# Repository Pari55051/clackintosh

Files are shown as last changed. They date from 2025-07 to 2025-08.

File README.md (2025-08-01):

# Clackintosh
a wireless mechanical keyboard, with 75% layout (81 keys) and a rotary encoder. 
this accompanies my other hardware projects, namely, Clackinntosh Jr. (a macropad), Clackade (a small, very basic PCB-based game console), and Clickster (mouse based on Bambu Lab's Mouse Kit)

## Features
- 75% layout (81 keys) + a rotary encoder
- based on nice!nano v2 MCU
- has underglow LEDs to light up the side-printed keycaps
- hotswappable switches (Cherry MX Red/Brown)
- wireless with 10000mah battery
- ~ 4° tilt for ergonomics
- ZMK firmware
- a blank white case to put some stickers on it!
- an accompanying wristrest

## Images

## General
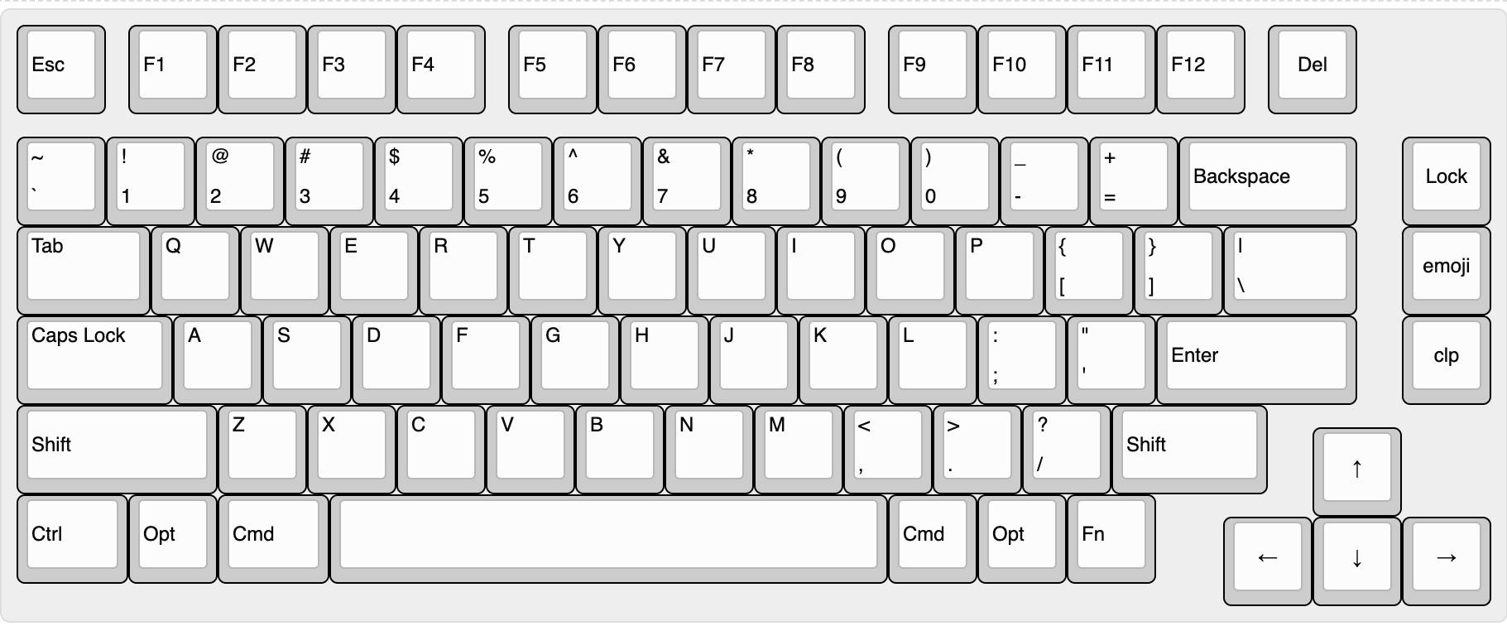
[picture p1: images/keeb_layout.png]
keeb layout

> not the assembled version, i'm hoping for it to look like this with the keycap set
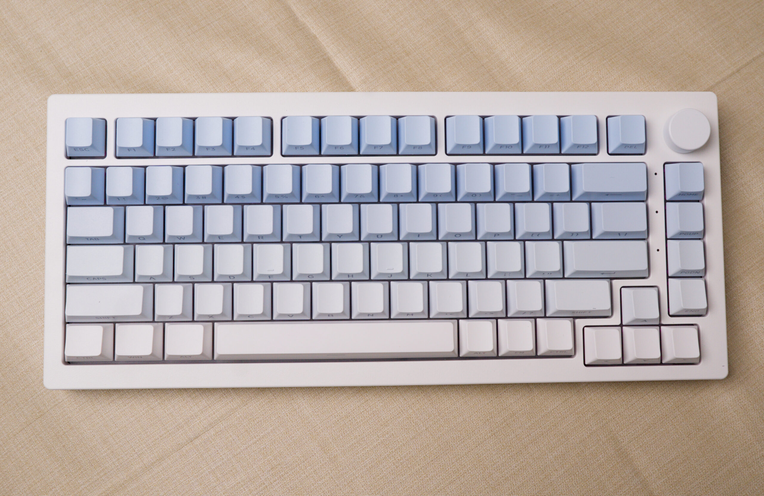
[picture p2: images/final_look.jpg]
wanted look


### Schematic
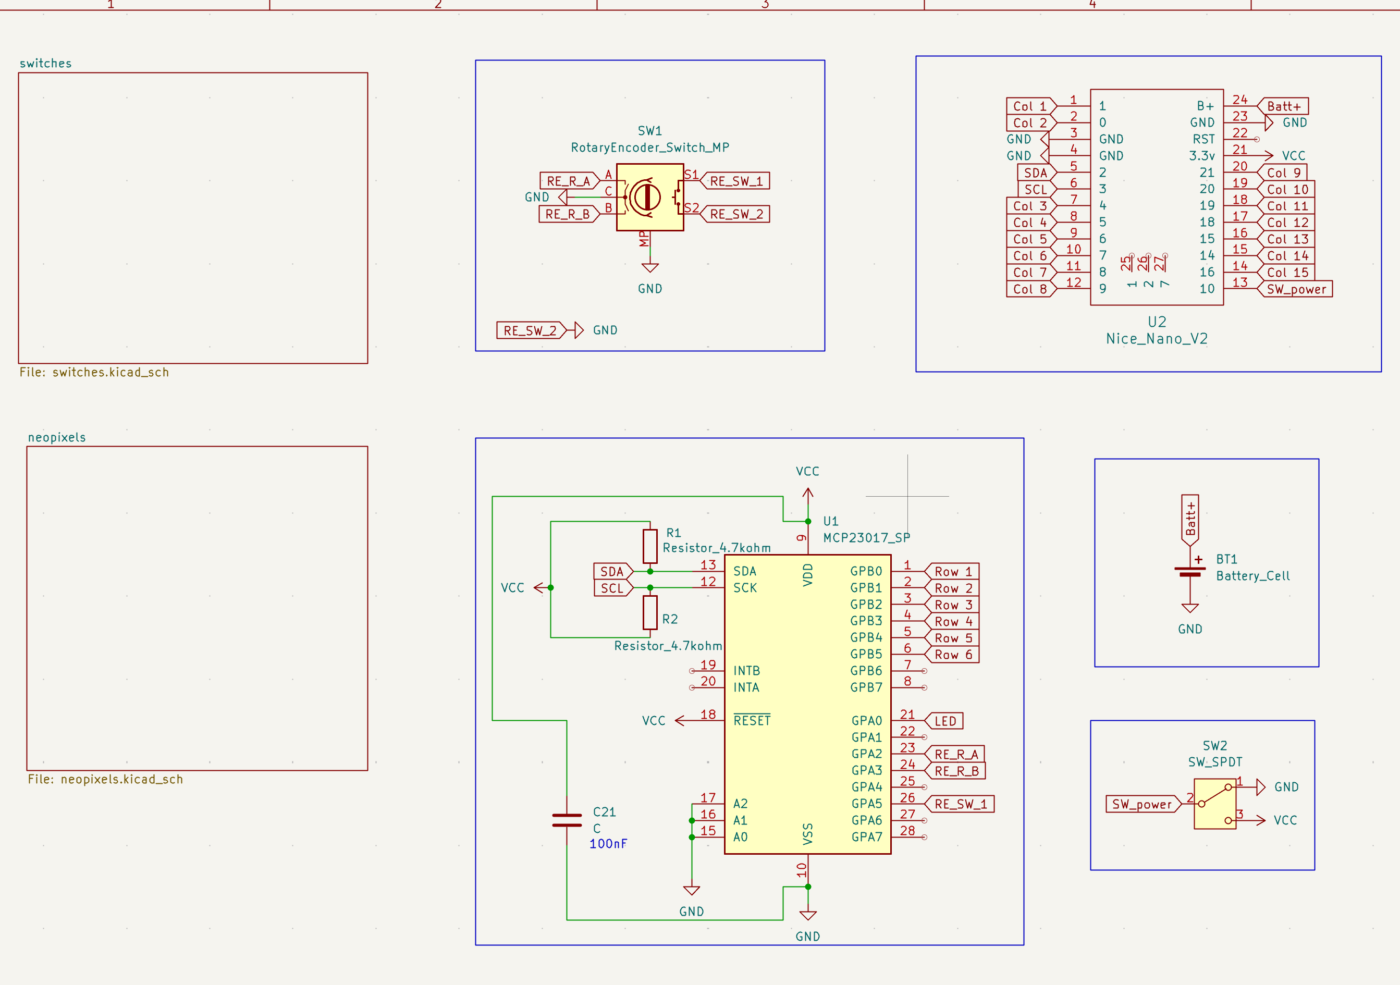
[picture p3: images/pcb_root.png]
pcb_root

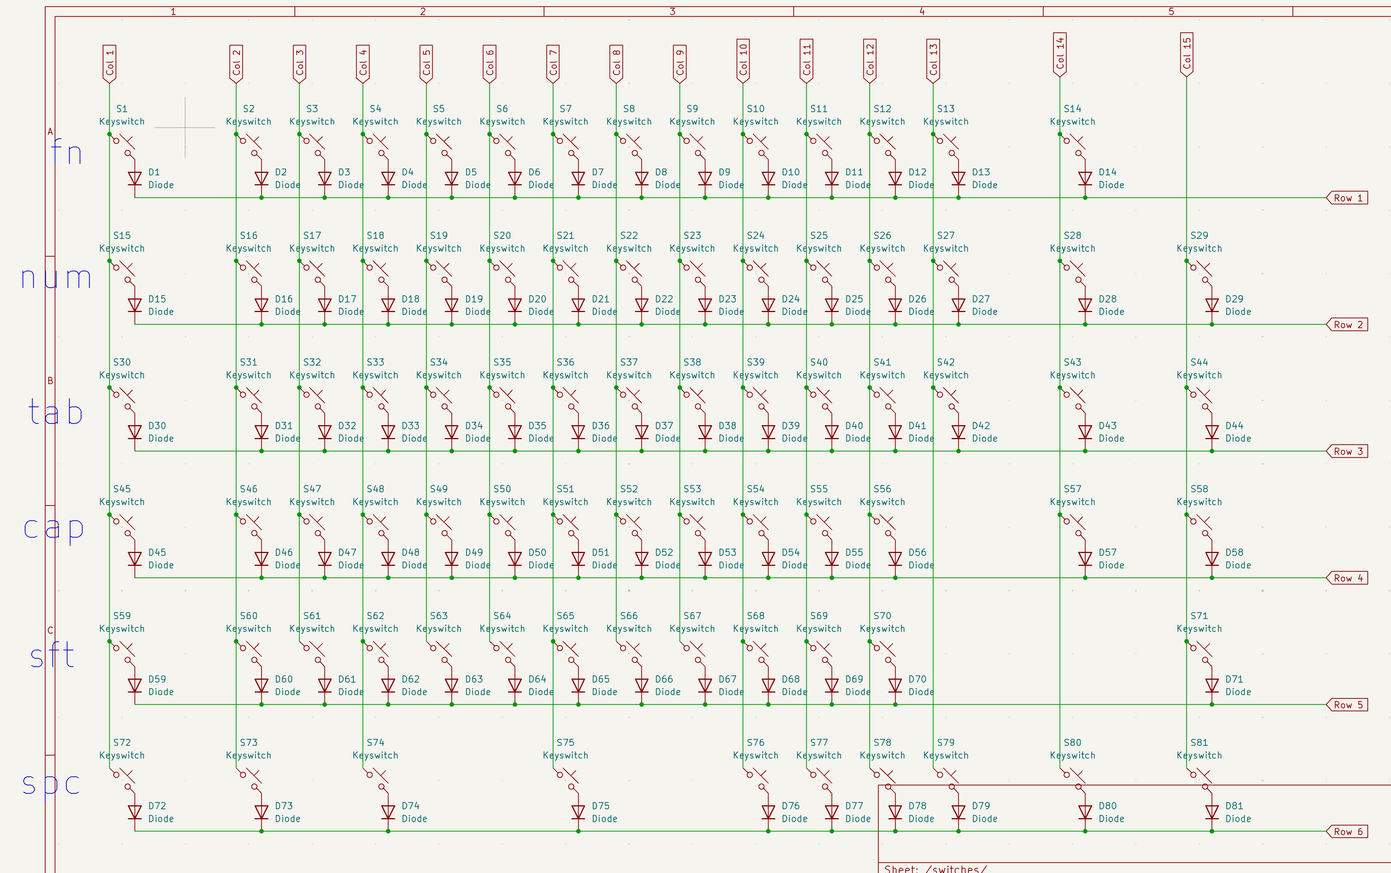
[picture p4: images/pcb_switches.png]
pcb_switches

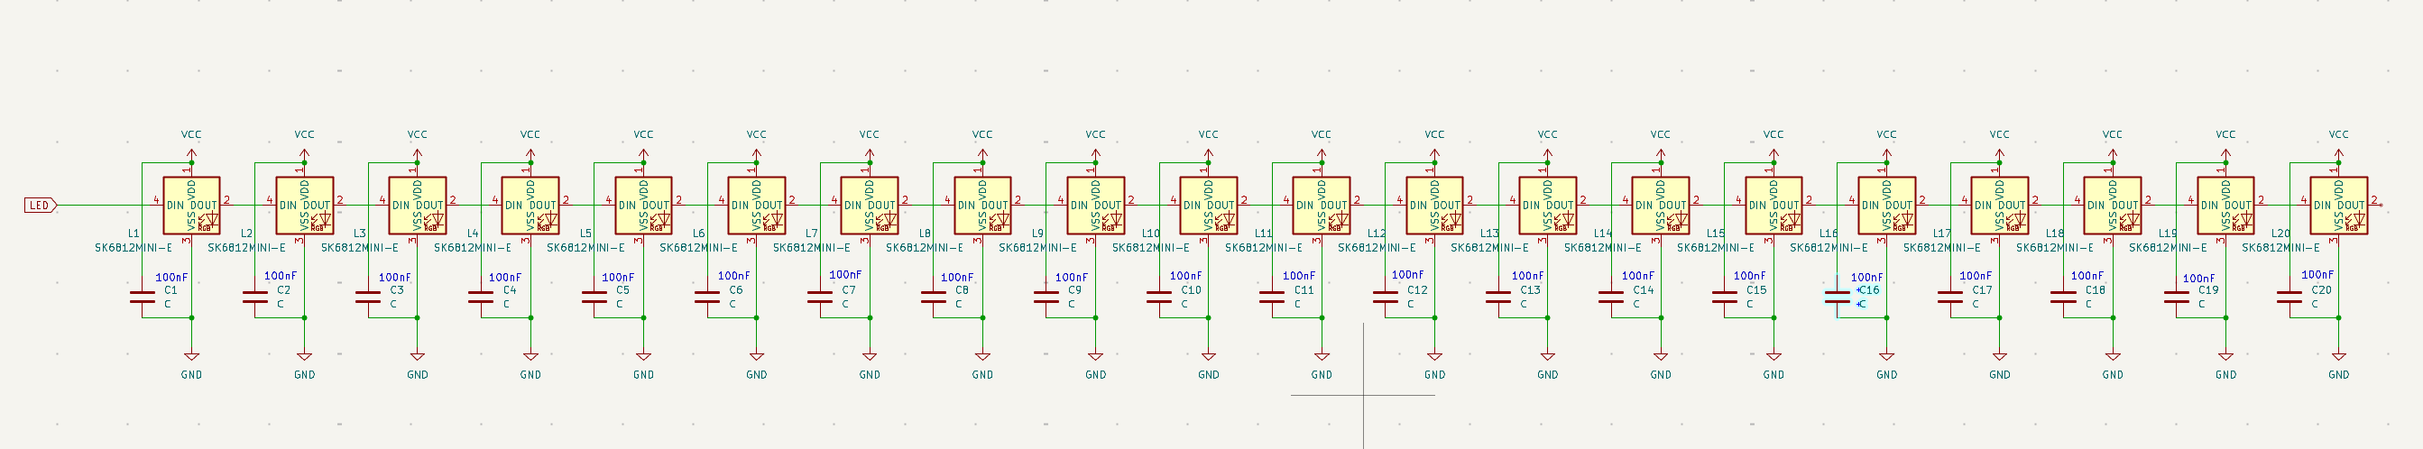
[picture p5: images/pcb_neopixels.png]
pcb_neopixels


### PCB
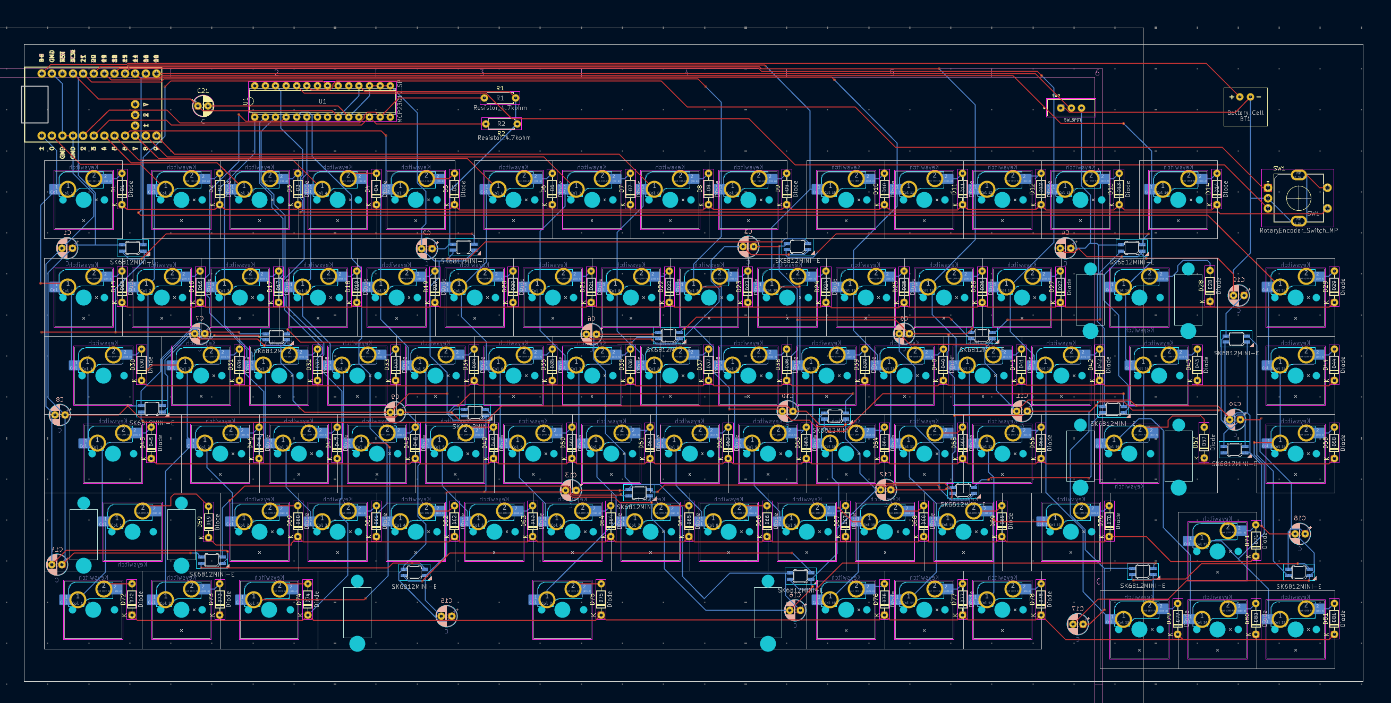
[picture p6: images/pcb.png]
pcb view

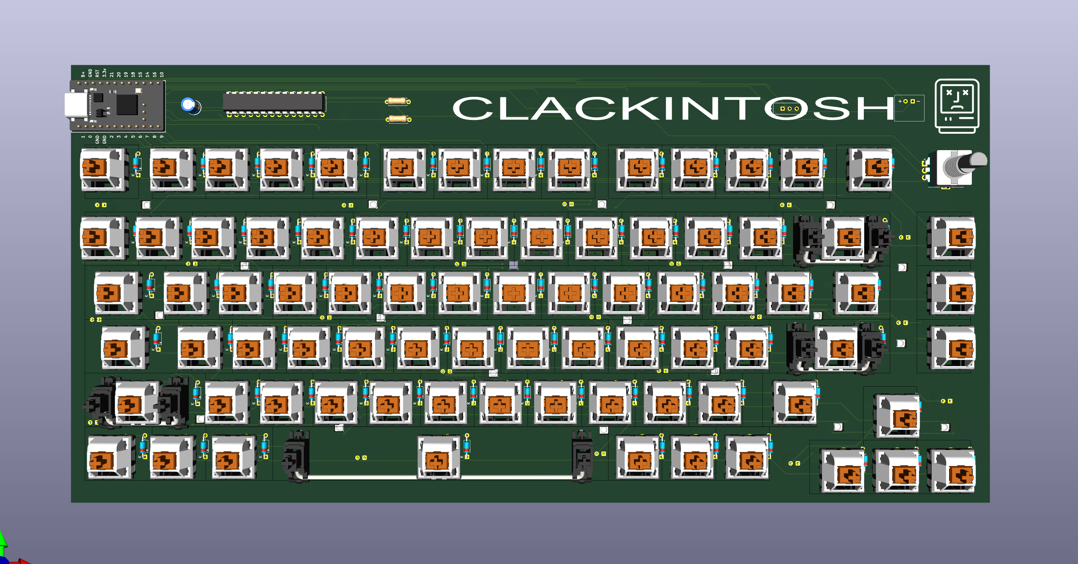
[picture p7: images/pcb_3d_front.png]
pcb 3d_front

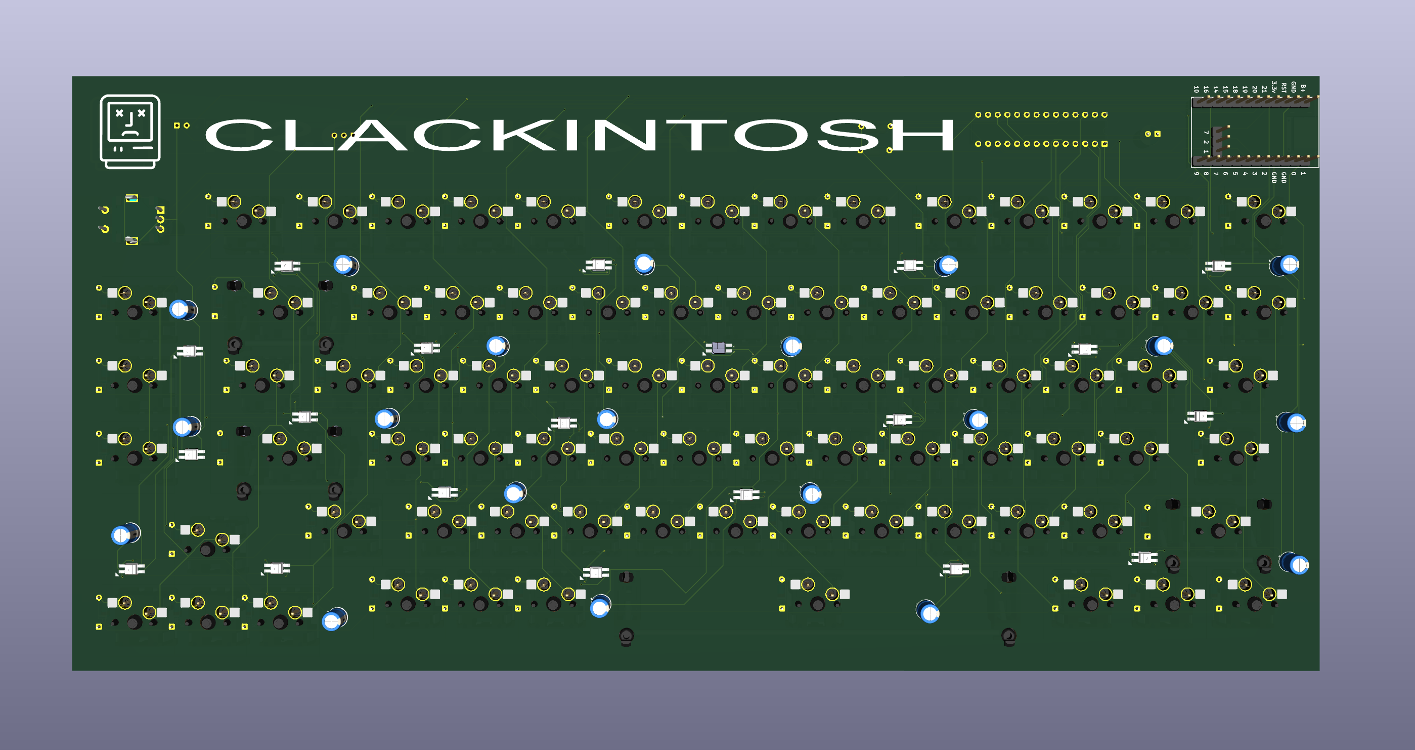
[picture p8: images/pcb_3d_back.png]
pcb 3d_back

> this would have hotswappable switches, i did not add t to the pcb since i had to manually add for each key, the footprint is chosen appropriately

### Case
> the case has space on top to add custom stickers (hackclub merch ones, since i don't know where to put them)
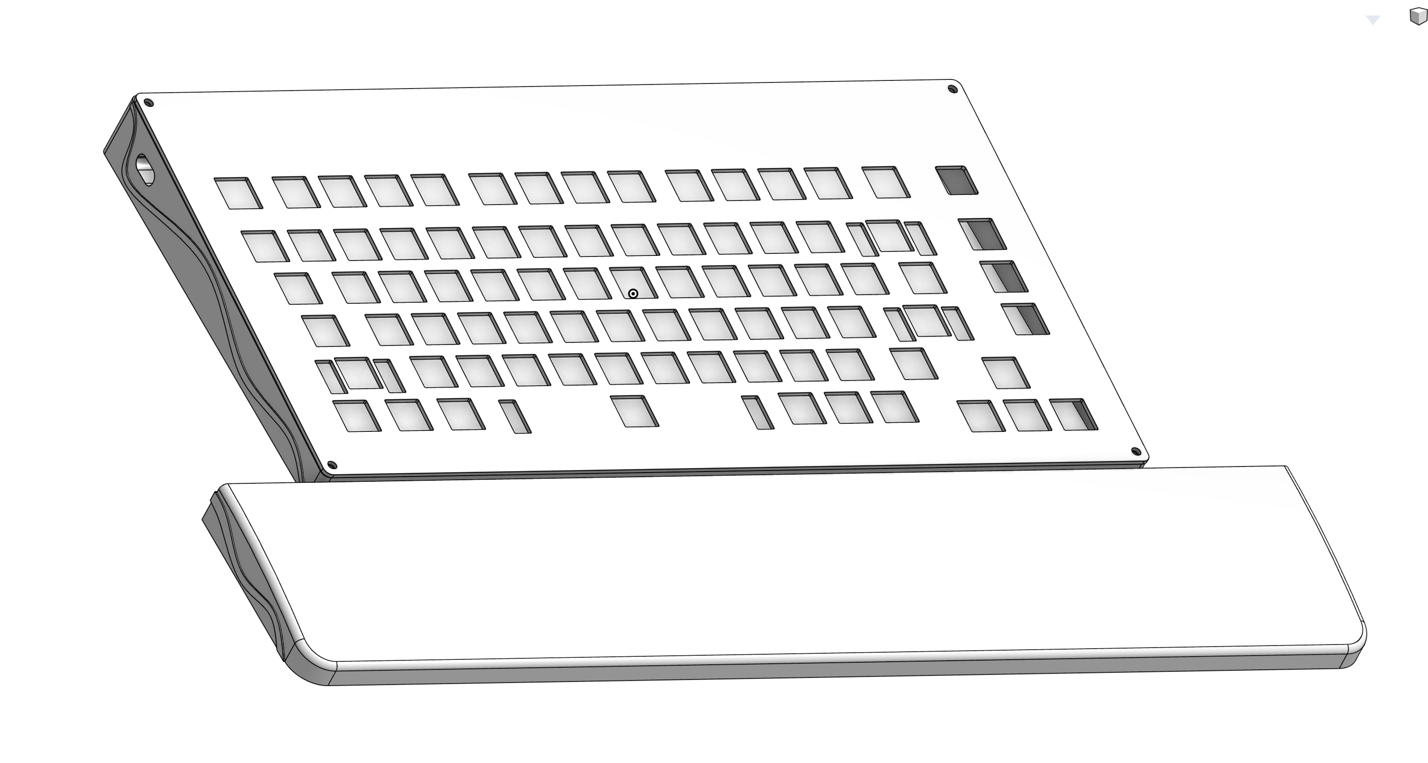
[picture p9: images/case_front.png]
case front

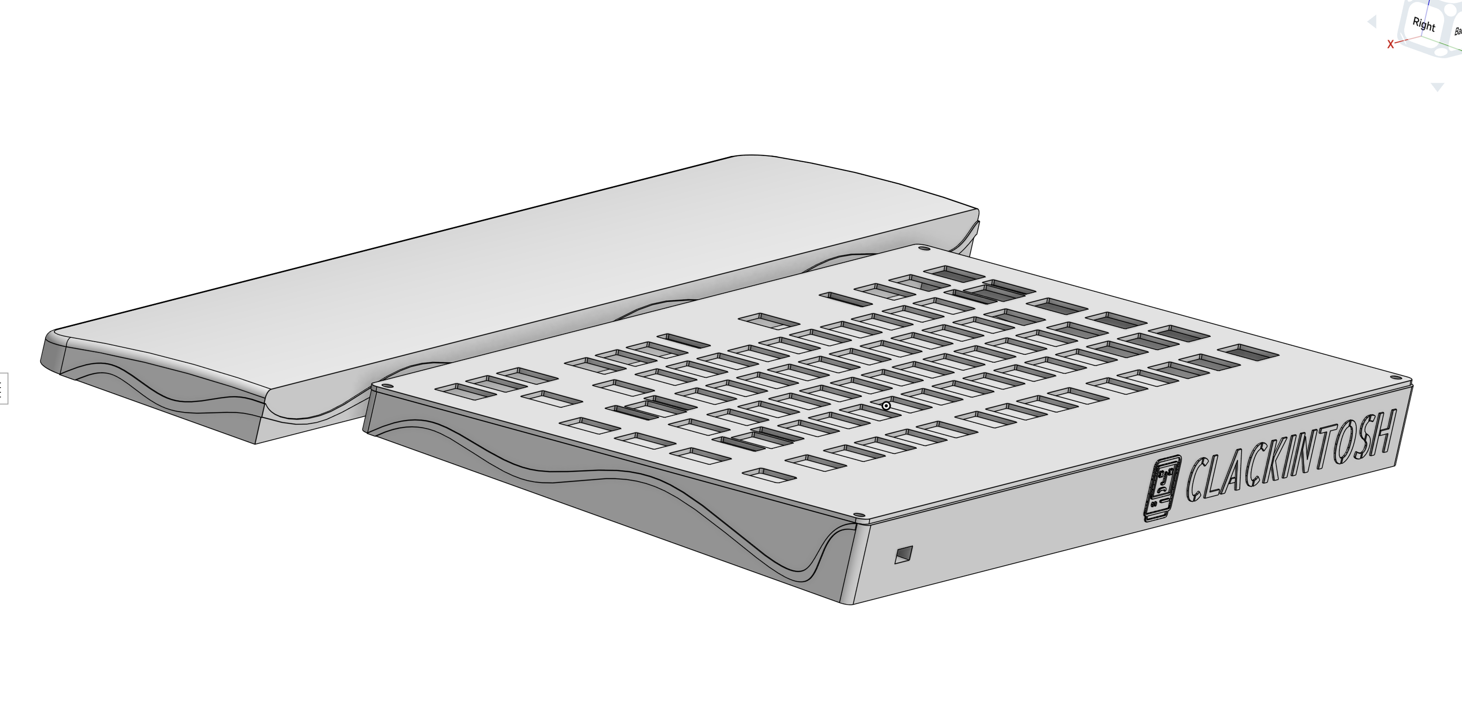
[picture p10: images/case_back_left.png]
case back


### Full Assembly
> the fully assembled one's PCB is not placed properly (not rotated to the correct angle) since there was some unknwon error in onshape where i could not rotate the thing, whenever i tried to rotate it would load and then no changes would occur. i tried my best to rotate it, and debug this but could not do so.
> will update the images if i'm able to do so in the future

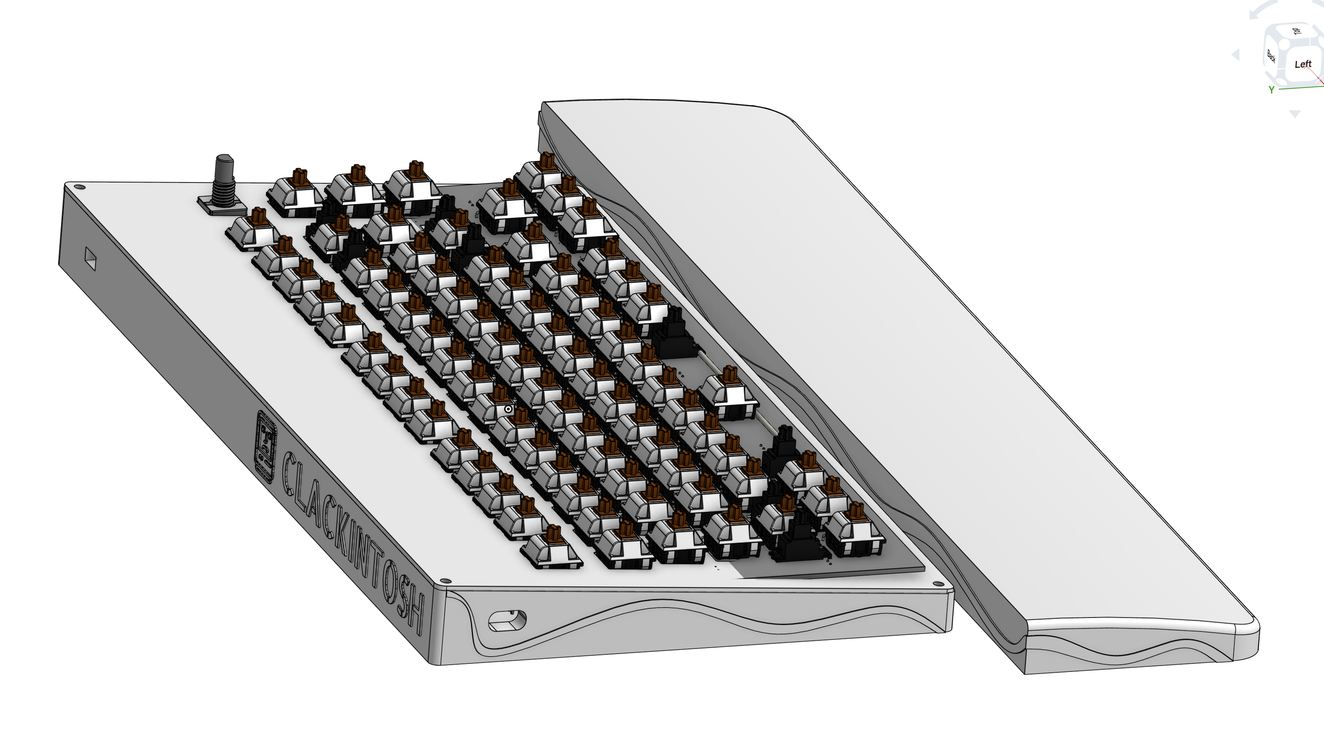
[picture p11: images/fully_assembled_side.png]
case_fully assembled side

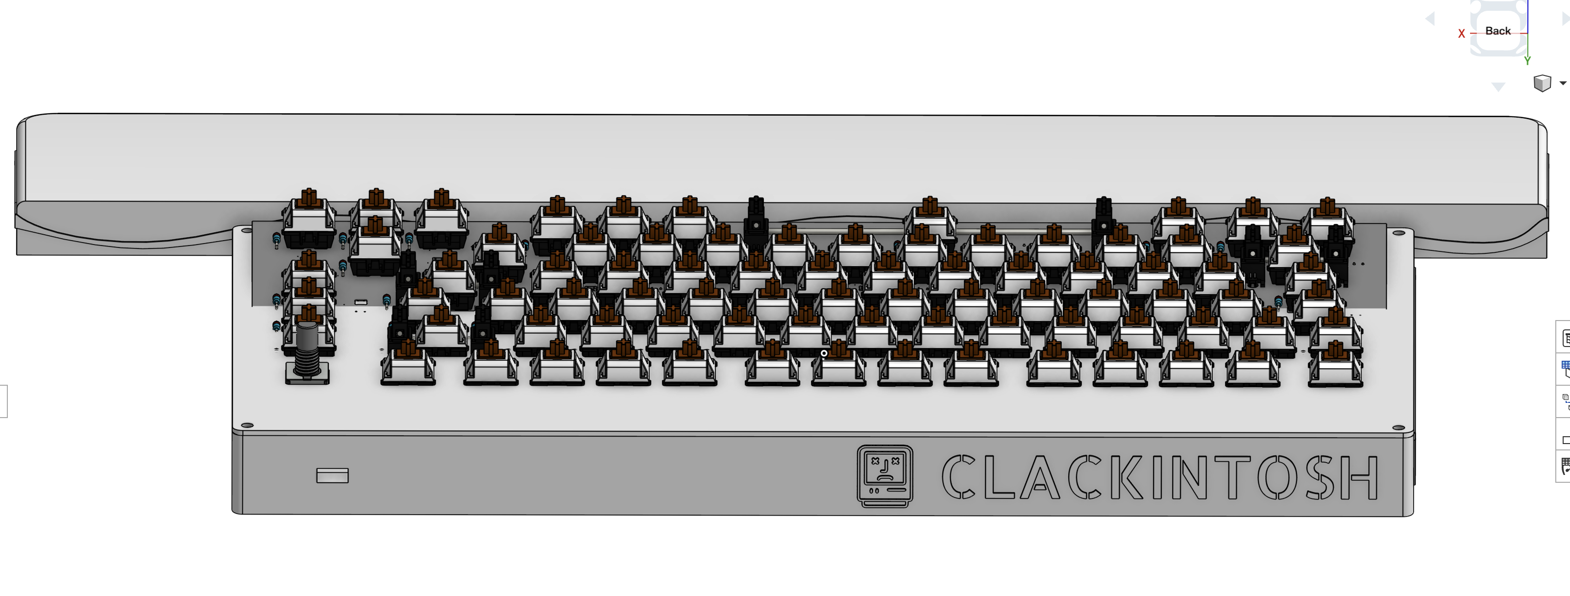
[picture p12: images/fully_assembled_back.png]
case_fully assembled back


## Challenges
the biggest challenge i faced was getting the schematcs right. i got the thing reviewed multiple times (on reddit, on #highway), added components, removed components, re-added components (capacitors, i'm looking at you)
another challenge was the case CAD, which had unexpected errors.

## BOM
|S. | Item | Quantity | Price | Link | Notes|
|---|---|---|---|---|---|
|1.| Case (incl. wristrest) | 1 | - | - | printed though printing legion|
|2.| Knob for rotary encoder | 1 | - | - | printed though printing legion |
|3.| Switches - Akko V3 Cream Black Pro | 81 | Rs.2398 ($27.41) | [StacksKB](https://stackskb.com/store/akko-v3-cream-black-pro-switch-pack-of-45/) | ordered two since it is a packof 48, free shipping |
|4.| Hotswappable Sockets | 81 | Rs.1090 ($12.46) [incl. shipping of about $1.14] | [Neo Macro](https://neomacro.in/products/kailh-mx-hotswap-socket?variant=49467139227926) | 9 qty. ordered, since it is a set of 10 |
|5.| Stabilizers | 3 (2u) + 1 (6.5u) | Rs.1585 ($18.12) | [StacksKB](https://stackskb.com/store/durock-smokey-screw-in-stabilizers-v2/) | no shipping  charge |
|6.| Rotary Encoder - EC11 | 1 | Rs.172 ($1.97) | [Amazon.in](https://www.amazon.in/CentIoT-Encoder-Digital-Potentiometer-Control/dp/B0888RWNM1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,aps,248&sr=8-3) | - |
|7.| Keycaps Set - side printed blue | 1 | Rs.1299 ($14.85) | [StacksKB](https://stackskb.com/store/veekos-gradient-keycaps-cherry-profile-135-keys/) | - |
|8.| Nice!Nano v2 --> Pro Micro | 1 | Rs.758 ($8.66) [incl. $1.13 shipping] | [Probots](https://probots.co.in/pro-micro-nrf52840-development-board-compatible-with-nice-nano-v2-0.html) | compatible with nice!nano, and wayy cheaper |
|9.| SK6812Mini-E neopixels | 20 | Rs.752.23 ($8.60) [incl. $3.74 shipping] | [LCSC](https://lcsc.com/product-detail/RGB-LEDs-Built-in-IC_OPSCO-Optoelectronics-SK6812MINI-E_C5149201.html) | for underglow for keycap visibility, not available anywhere else |
|10.| 100nF Capacitors | 21 | Rs.210 ($2.40) | [Amazon.in](https://www.amazon.in/100pcs-Ceramic-disc-Capacitor-100nf/dp/B08FB2NZ1L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,aps,259&sr=8-1) | decoupling + used in i2c expander |
|11.| I2C Expander - MCP23017 | 1 | Rs.258.99 ($2.96) | [RoboticsDNA](https://roboticsdna.in/product/mcp23017-e-sp-microchip-i-o-expander-16-bit-i2c-serial-1-8-v-5-5-v-dip-28-pins/) | short on GPIOs, had to use it |
|12.| Resitors - 4.7k ohm | 2 | Rs.9 ($0.10) | [Robocraze](https://robocraze.com/products/4-7k-resistor-pack-of-10?_psq=4.7k&_v=1.0) | pullups for i2c|
|13.| Diodes - 1N4148 though-hole | 81 | Rs.135 ($1.54) | [StacksKB](https://stackskb.com/store/1n4148-through-hole-diode/) | - |
|14.| 100000mah Battery | 1 | Rs.667 ($7.62) | [Amazon.in](https://www.amazon.in/Portronics-Luxcell-Charging-Output-Button/dp/B0CQK537RQ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,aps,203&sr=8-14&th=1) | for long battery life, using this since this is wayy cheaper then the li-po battery |
|15.| M3x12mm screws | 4 | Rs.159 ($1.82) | [Amazon.in](https://www.amazon.in/gp/product/B07XY78Q73?smid=A1QGCD9W0FP1ZA&th=1) | to assemble the case |
|16.| M3x5mm heatset inserts | 4 | Rs.170 ($1.94) | [Amazon.in](https://www.amazon.in/gp/product/B0CX1BS7DJ?smid=A1QGCD9W0FP1ZA&psc=1) | to assemble the case |
|17.| Slide Switch (SPDT) | 1 | Rs.14 ($0.16) | [Robocraze](https://robocraze.com/products/slide-switch-3-pin-2-way-spdt?_psq=spdt&_v=1.0) | to turn the keeb on/off |
|18.| PCB | 5 (default via jlcpcb) | Rs.2780.57 ($31.78) | - | - | 

**TOTAL AMOUNT = Rs.12,457.79 ($142.39) [excl. shipping for printing legion]**

## Credits

- made by: [unowen](https://github.com/pari55051)
- inspiration: some image i found on google
- schem: shout out to all the people who helped me fixed the thing
- case: shout out to "One For Freedom" for helping resolve errors in the cad
- canva: for base version of the logo, which i had to edit later in figma
- StacksKB: "final look" image from website

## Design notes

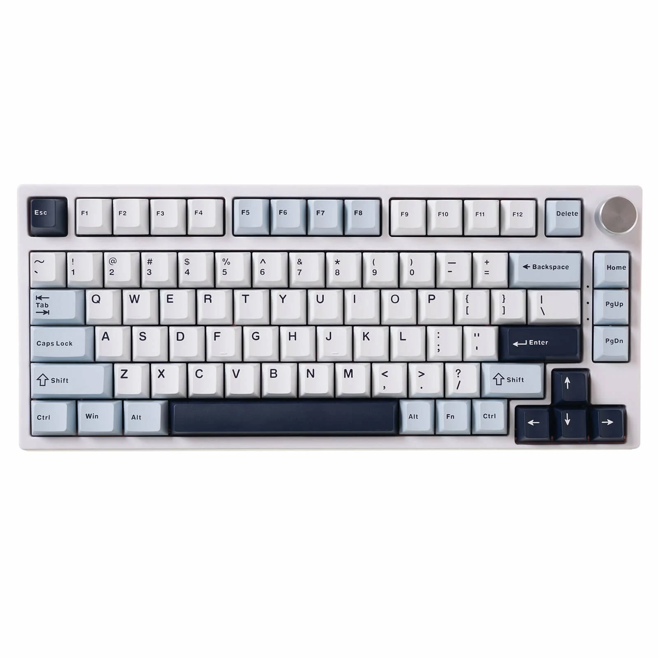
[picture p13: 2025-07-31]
images/inspiration.png

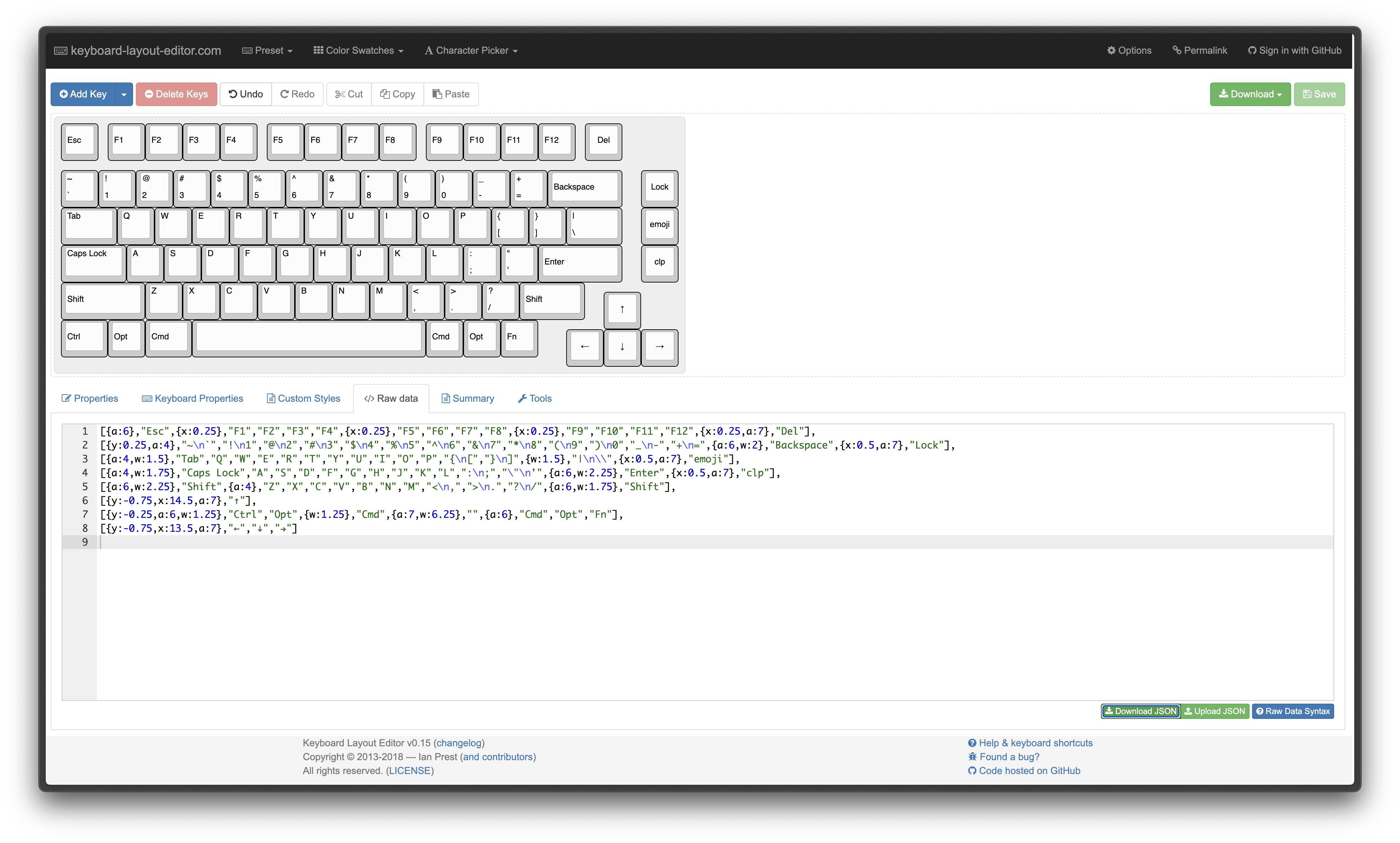
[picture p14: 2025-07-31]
images/layout_raw.png

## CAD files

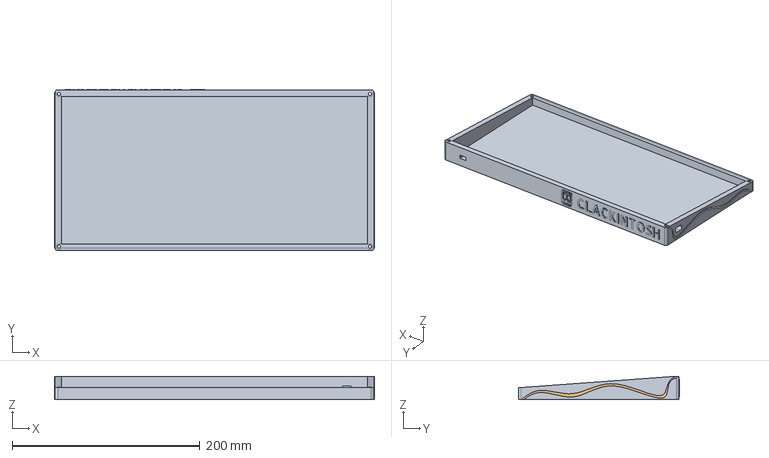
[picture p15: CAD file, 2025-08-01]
CAD/assembly_noPCB.step
340.7 x 171.8 x 25.0 mm

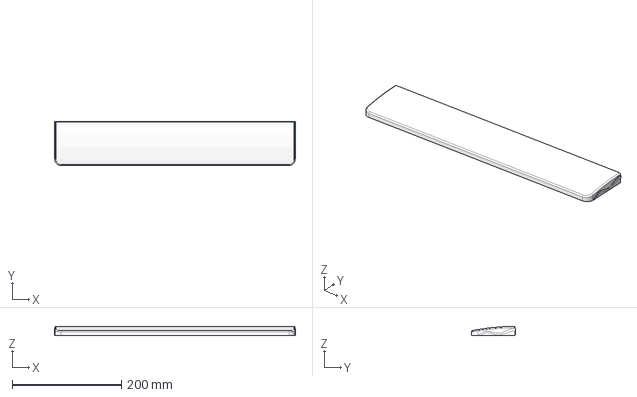
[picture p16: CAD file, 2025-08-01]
CAD/wristrest.step
441.0 x 80.5 x 17.0 mm

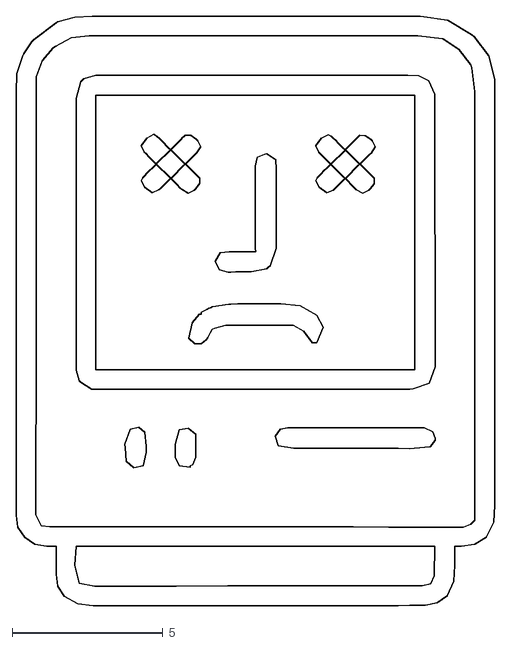
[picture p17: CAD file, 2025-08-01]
images/logo.dxf
15.9 x 19.5

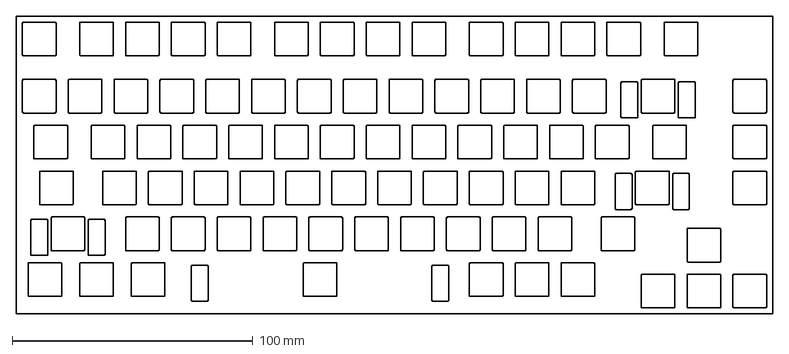
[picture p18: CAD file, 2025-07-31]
PCB/Plate.dxf
314.3 x 123.8 mm

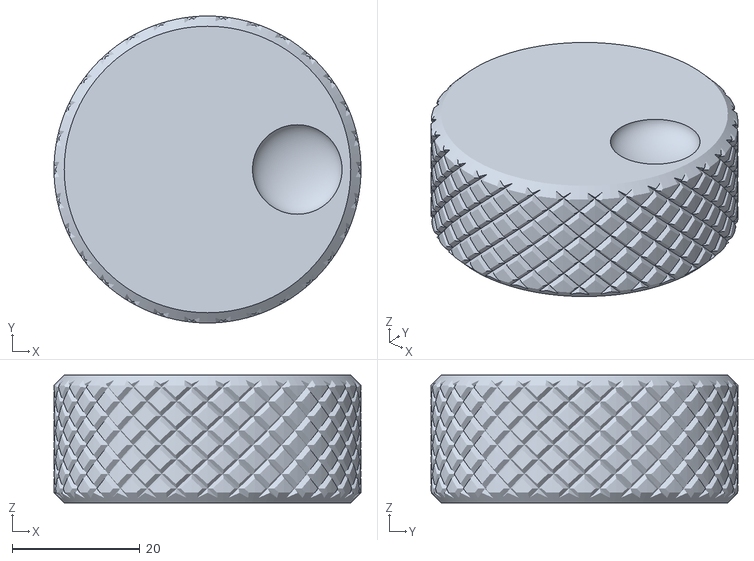
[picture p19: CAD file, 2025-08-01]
CAD/RE_knob.stl
48.0 x 48.0 x 20.0

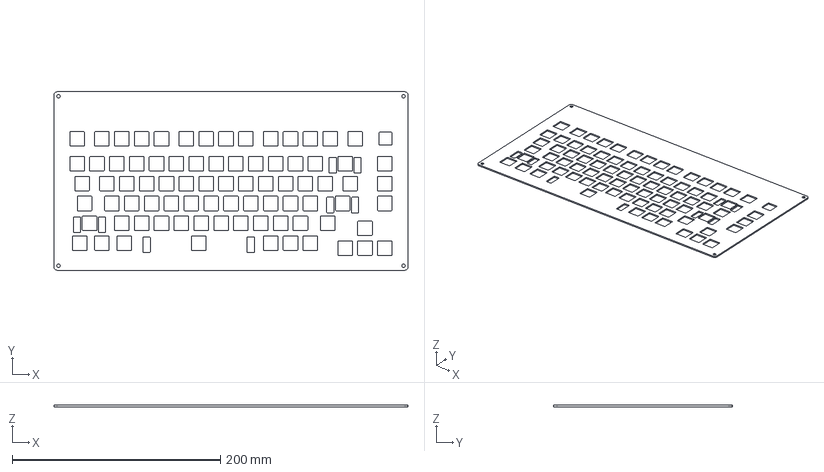
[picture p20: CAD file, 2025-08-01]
CAD/plate.step
339.7 x 171.3 x 1.50 mm

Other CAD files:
production/base.step
CAD/base.step

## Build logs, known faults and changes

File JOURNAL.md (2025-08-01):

---
title: Clackintosh
author: unowen
description: a wireless mechanical keebto go with my mac
created_at: "2025-07-20"
completed_on: "2025-07-31"
tota time: "25.5hr"
---

---
# July 20th: Research
I researched about building mechanical keyboard, made the inital list of features that I am planning to include, explored websites related to mechanical keyboards (ranging from online stores, to various subreddits and youtube videos). Also, looked at some already approved mech keyboards projects submitted for highhway for more info + inspiration.

**(Initial) List of Features:**
- wireless connectivity (and therefore bluetooth + battery) [decided upon nice!nano v2 and li-ion 1100maH battery for now]
- layout = TKL/75% (depending upon if i wish to include a i2c expander or not in pcb) => 87/88 keys OR 81/84/85 keys
- dropping the rotary encoder for now
- sound = thoc (some kind of linear/tactile switches --> prob mx red/brown/black, might look at gateron for cheaper options) (will put some packing foam underneath as mod, not planning to include proper foam for mech keeb yet)
- keycaps --> white-to-blue gradient side printed keycaps (the printed label should be translucent so that rgb light can shine through)
- 3D printed case --> might inclide a nice tilt for better ergo --> white coloured
- per-key rgb via sk2852mini-e leds

**Total time spent: 1.5hr**
---

# July 21st - July 22nd: Schematic for PCB
Made the schematic for the keyboard's pcb. this took a lot of googling, asking in #highway in hackclub's slack, and also some perplexity-done research (because why not) (cross-checked everyhting though).
Made the following updates to the overall project plans as well:
- decided to go ahead with the 75% layout - 81 keys
- added the rotary encoder (since i had to use an i2c expander anyway becuase of the neopixels)

Found a design (mostly just the layout) inspiration:
keeb inspo

Screnshot of the Schem:
Screenshot 2025-07-23 at 12 39 24 AM
Screenshot 2025-07-25 at 11 38 41 PM

**Total time spent: 6.5hr**
---

# July 24th: PCB Schem Touchups
Edited the schem to better account for battery life, etc. Made the following updates:
- found a 10000mah battery for powering the setup (added symbol to kicad schem, yes i did not have it before)
- added capacitor + resisitor to neopixels chain (still not sure which specifications ones => decided between (220-470uF range for caps)? and 330-470ohm range for resistor)
- found out that since i only need a underglow, 20 neopixels would be enough instead of all 82 for per-key rgb
- asked in some places (#highway slack and reddit] for cross-verifying my schematic (always good to make sure) [link to reddit post]

Screenshots of the Schem: (better organized in sub-sheets)
  root_schem
swithces_schem
neopixels_schem

**Total time spent: 3.5hr**
---

# July 27th - July 28th: PCB Schem Touchups 2 + PCB Placement
**Made some major edits to the schem:**
- changed the key matrix to better resemble the actual keyboard
- added a slide switch (because, well, I forgot to do it before)
- added footprints

**PCB Placement**
- used Keyboard Layout Placer Plugin in KiCad to position the keys in the appropriate place as per decided layout
- made the decided layout in the Keyboard Layout Maker to get the json file
- placed the MCU, battery holder, etc.
- added 3D model for the switch, which i was adding on the worng side, fixed the issue there (took a lot of time)
- wiring is still left

did more research + parts sourcing work informally (i.e checked where all available and at which price range)

Screenshots of the Schem:
 switches_schem_new

Screenshots of the PCB (unwired):
pcb

Screenshot of the Keyboard Layout:
Keeb_Layout

plan for next ses: add 3d models to pcb + final checks for correctness, start with case CAD

**Total time spent: 4hr**
---

# July 29-30th: PCB Finalized + made Case
- added decoupling caps to neopixels after a lot of help from people
- did the final wiring of the pcb
- added 3d models to the pcb of the components

- made CAD base + plate for the keeb case
- updated layout json (it did not have a gap i wanted in between func. row and the num row (refer inspiration img))

(the case still has some issues i hope they fixed by tomorrow!)
error

**Total time spent: 5hr (took way too long becuase i had to manually add each key + erros in CAD)**
---

# July 31st: Keeb Finalize
- added 3d model of pcb to CAD
- finishing touches to case CAD
- re-verifying everything => found out battery needed some re-modelling of the case
- finalized repo for shipping

pcb_root
pcb_neopixels
pcb_switches
pcb
pcb_3d_front

**Total time spent: 2.5hr**
---

# Aug 1st: Resolving Issues
needed to update the case and the pcb as told by reviewer

Made the following changes:
- added a wristrest to the keeb case
- created and added a logo to the case + PCB
- added wave patterns on the case and wrist rest to match the blue gradient keycap theme
- added a final look inspiration
- let go of the sticker grafitti wall idea, will put a few aesthetic matching ones only now
- got the decoupling capacitors closer to the neopixels
- added labels to all capacitors for values
- updated value for pullup resistors on i2c expander

<all updated images in the readme>

**Total Time Spend: 2.5hr**
---

**TOTAL TIME SPENT = 23hr (schem took wayy too long)**

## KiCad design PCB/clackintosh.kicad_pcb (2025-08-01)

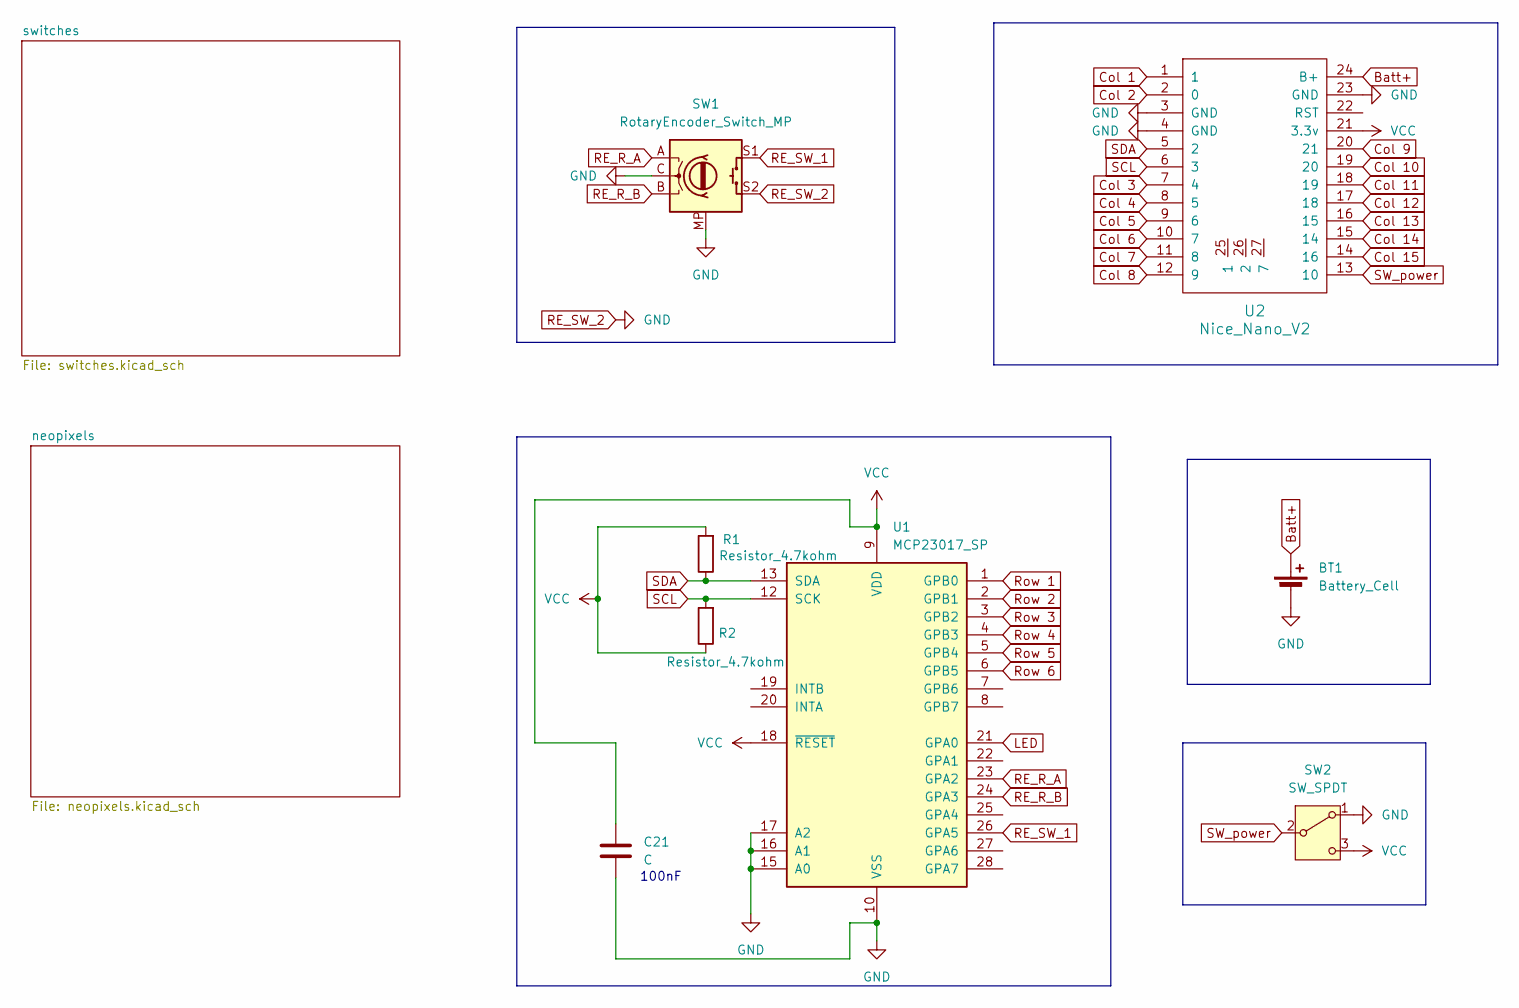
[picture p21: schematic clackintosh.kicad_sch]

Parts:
BT1: Battery_Cell; Battery
C21: C; CP_Radial_D5.0mm_P2.50mm
R1, R2: Resistor_4.7kohm; R_Axial_DIN0207_L6.3mm_D2.5mm_P7.62mm_Horizontal
SW1: RotaryEncoder_Switch_MP; RotaryEncoder_Alps_EC11E-Switch_Vertical_H20mm
SW2: SW_SPDT; SW_MINI-SPDT-SW
U1: MCP23017_SP; DIP-28_W7.62mm
U2: Nice_Nano_V2

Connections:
Batt+: BT1.1 (+), U2.24 (B+)
Col 1: U2.1; also elsewhere on the board
Col 2: U2.2 (0); also elsewhere on the board
Col 3: U2.7 (4); also elsewhere on the board
Col 4: U2.8 (5); also elsewhere on the board
Col 5: U2.9 (6); also elsewhere on the board
Col 6: U2.10 (7); also elsewhere on the board
Col 7: U2.11 (8); also elsewhere on the board
Col 8: U2.12 (9); also elsewhere on the board
Col 9: U2.20 (21); also elsewhere on the board
Col 10: U2.19 (20); also elsewhere on the board
Col 11: U2.18 (19); also elsewhere on the board
Col 12: U2.17 (18); also elsewhere on the board
Col 13: U2.16 (15); also elsewhere on the board
Col 14: U2.15 (14); also elsewhere on the board
Col 15: U2.14 (16); also elsewhere on the board
LED: U1.21 (GPA0); also elsewhere on the board
RE_R_A: SW1.A, U1.23 (GPA2)
RE_R_B: SW1.B, U1.24 (GPA3)
RE_SW_1: SW1.S1, U1.26 (GPA5)
RE_SW_2: BT1.2 (-), C21.2, SW1.C, SW1.MP, SW1.S2, SW2.1 (A), U1.10 (VSS), U1.15 (A0), U1.16 (A1), U1.17 (A2), U2.3 (GND), U2.4 (GND), U2.23 (GND); also elsewhere on the board
Row 1: U1.1 (GPB0); also elsewhere on the board
Row 2: U1.2 (GPB1); also elsewhere on the board
Row 3: U1.3 (GPB2); also elsewhere on the board
Row 4: U1.4 (GPB3); also elsewhere on the board
Row 5: U1.5 (GPB4); also elsewhere on the board
Row 6: U1.6 (GPB5); also elsewhere on the board
SCL: R2.2, U1.12 (SCK), U2.6 (3)
SDA: R1.1, U1.13 (SDA), U2.5 (2)
SW_power: SW2.2 (B), U2.13 (10)
VCC: C21.1, R1.2, R2.1, SW2.3 (C), U1.9 (VDD), U1.18 (~RESET), U2.21 (3.3v); also elsewhere on the board

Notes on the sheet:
100nF

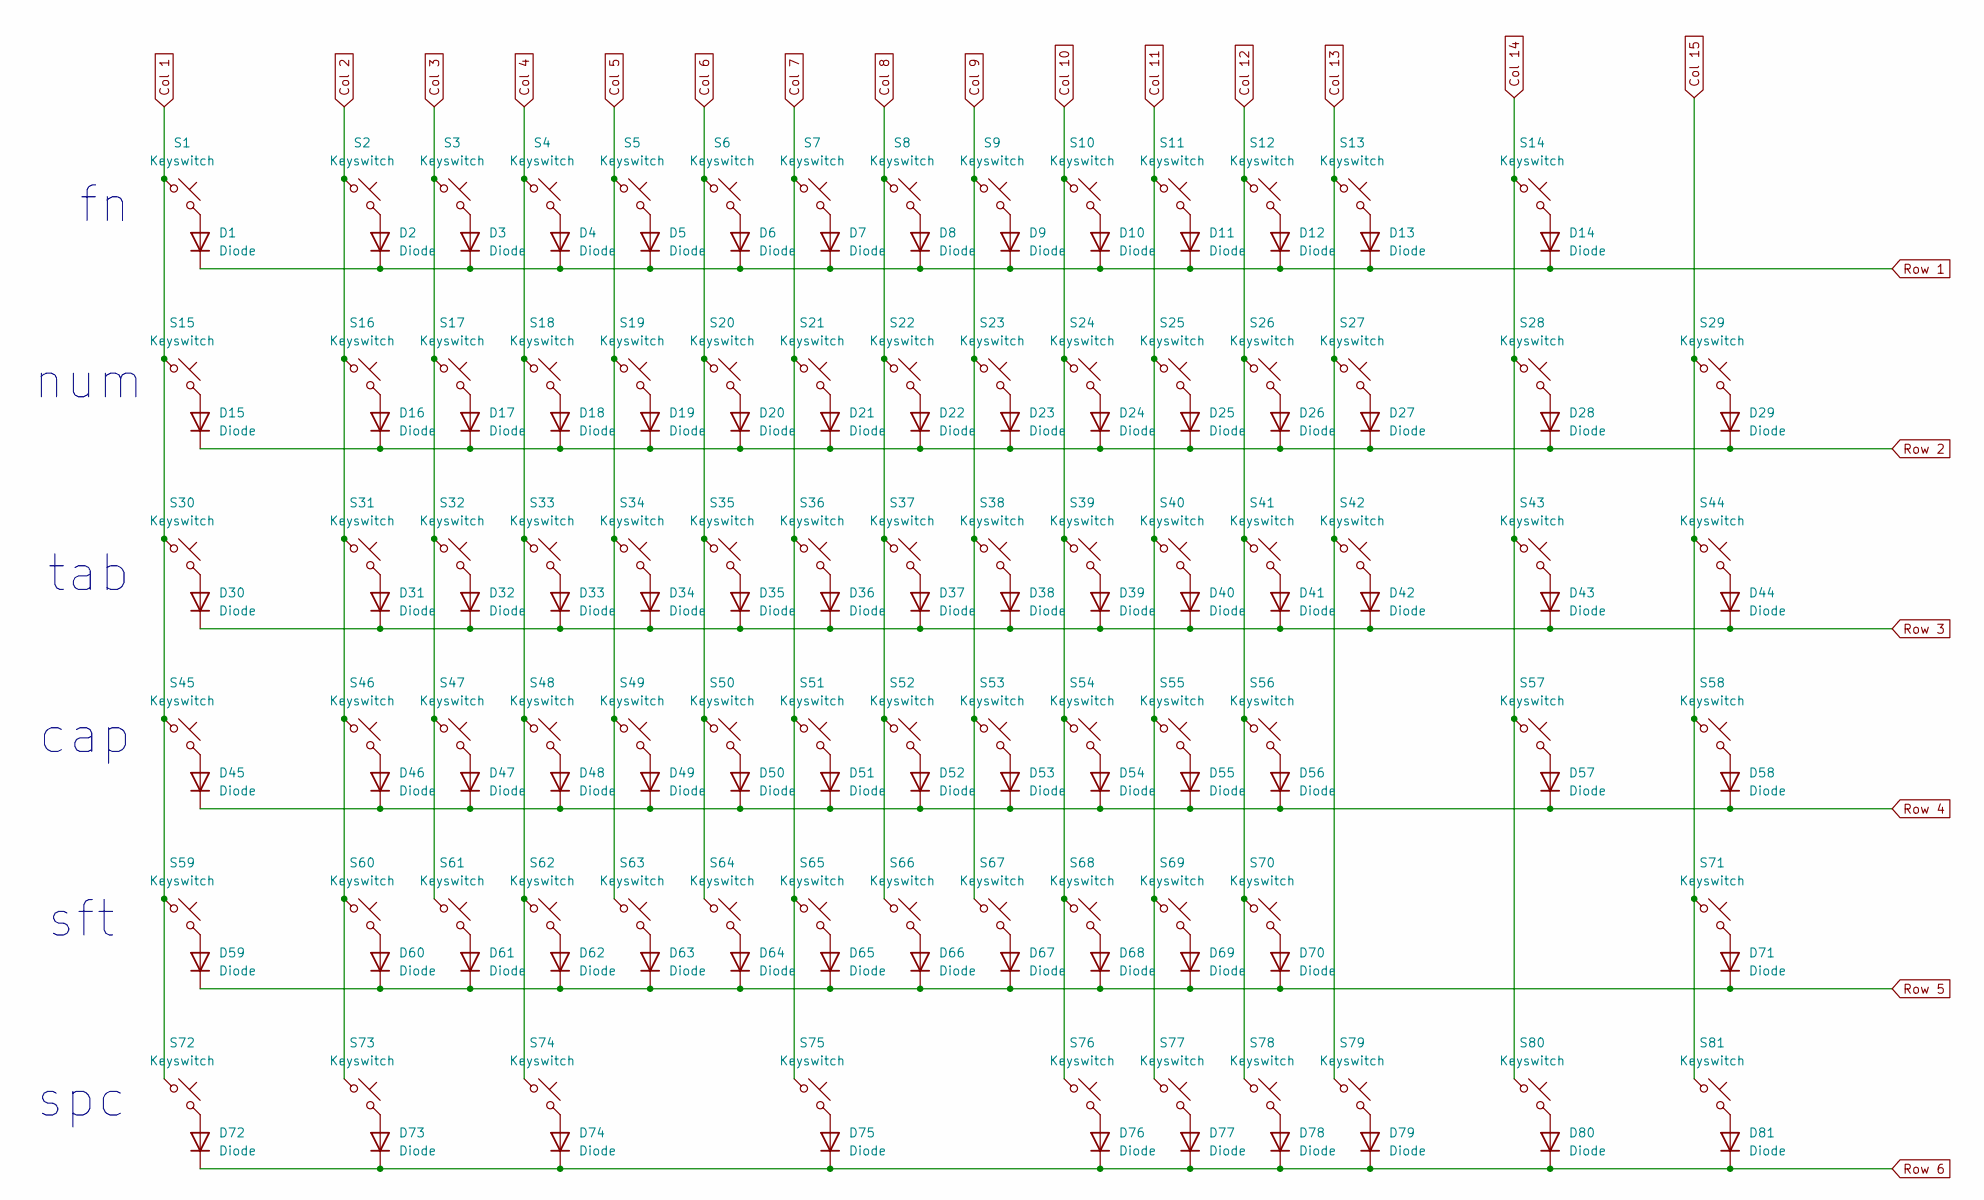
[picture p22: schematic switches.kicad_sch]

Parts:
D1, D2, D3, D4, D5, D6, D7, D8, D9, D10, D11, D12, D13, D14, D15, D16, D17, D18, D19, D20, D21, D22, D23, D24, D25, D26, D27, D28, D29, D30, D31, D32, D33, D34, D35, D36, D37, D38, D39, D40, D41, D42, D43, D44, D45, D46, D47, D48, D49, D50, D51, D52, D53, D54, D55, D56, D57, D58, D59, D60, D61, D62, D63, D64, D65, D66, D67, D68, D69, D70, D71, D72, D73, D74, D75, D76, D77, D78, D79, D80, D81: Diode; D_DO-35_SOD27_P7.62mm_Horizontal
S1, S2, S3, S4, S5, S6, S7, S8, S9, S10, S11, S12, S13, S14, S15, S16, S17, S18, S19, S20, S21, S22, S23, S24, S25, S26, S27, S29, S31, S32, S33, S34, S35, S36, S37, S38, S39, S40, S41, S42, S44, S46, S47, S48, S49, S50, S51, S52, S53, S54, S55, S56, S58, S60, S61, S62, S63, S64, S65, S66, S67, S68, S69, S70, S71, S73, S76, S77, S78, S79, S80, S81: Keyswitch; MX_Hotswap_1.00u
S28: Keyswitch; MX_Hotswap_2.00u
S30, S43: Keyswitch; MX_Hotswap_1.50u
S45: Keyswitch; MX_Hotswap_1.75u
S57, S59: Keyswitch; MX_Hotswap_2.25u
S72, S74: Keyswitch; MX_Hotswap_1.25u
S75: Keyswitch; MX_Hotswap_6.25u

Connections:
Col 1: S1.1, S15.1, S30.1, S45.1, S59.1, S72.1; also elsewhere on the board
Col 2: S2.1, S16.1, S31.1, S46.1, S60.1, S73.1; also elsewhere on the board
Col 3: S3.1, S17.1, S32.1, S47.1, S61.1; also elsewhere on the board
Col 4: S4.1, S18.1, S33.1, S48.1, S62.1, S74.1; also elsewhere on the board
Col 5: S5.1, S19.1, S34.1, S49.1, S63.1; also elsewhere on the board
Col 6: S6.1, S20.1, S35.1, S50.1, S64.1; also elsewhere on the board
Col 7: S7.1, S21.1, S36.1, S51.1, S65.1, S75.1; also elsewhere on the board
Col 8: S8.1, S22.1, S37.1, S52.1, S66.1; also elsewhere on the board
Col 9: S9.1, S23.1, S38.1, S53.1, S67.1; also elsewhere on the board
Col 10: S10.1, S24.1, S39.1, S54.1, S68.1, S76.1; also elsewhere on the board
Col 11: S11.1, S25.1, S40.1, S55.1, S69.1, S77.1; also elsewhere on the board
Col 12: S12.1, S26.1, S41.1, S56.1, S70.1, S78.1; also elsewhere on the board
Col 13: S13.1, S27.1, S42.1, S79.1; also elsewhere on the board
Col 14: S14.1, S28.1, S43.1, S57.1, S80.1; also elsewhere on the board
Col 15: S29.1, S44.1, S58.1, S71.1, S81.1; also elsewhere on the board
unnamed: D1.2 (A), S1.2
unnamed: D2.2 (A), S2.2
unnamed: D3.2 (A), S3.2
unnamed: D4.2 (A), S4.2
unnamed: D5.2 (A), S5.2
unnamed: D6.2 (A), S6.2
unnamed: D7.2 (A), S7.2
unnamed: D8.2 (A), S8.2
unnamed: D9.2 (A), S9.2
unnamed: D10.2 (A), S10.2
unnamed: D11.2 (A), S11.2
unnamed: D12.2 (A), S12.2
unnamed: D13.2 (A), S13.2
unnamed: D14.2 (A), S14.2
unnamed: D15.2 (A), S15.2
unnamed: D16.2 (A), S16.2
unnamed: D17.2 (A), S17.2
unnamed: D18.2 (A), S18.2
unnamed: D19.2 (A), S19.2
unnamed: D20.2 (A), S20.2
unnamed: D21.2 (A), S21.2
unnamed: D22.2 (A), S22.2
unnamed: D23.2 (A), S23.2
unnamed: D24.2 (A), S24.2
unnamed: D25.2 (A), S25.2
unnamed: D26.2 (A), S26.2
unnamed: D27.2 (A), S27.2
unnamed: D28.2 (A), S28.2
unnamed: D29.2 (A), S29.2
unnamed: D30.2 (A), S30.2
unnamed: D31.2 (A), S31.2
unnamed: D32.2 (A), S32.2
unnamed: D33.2 (A), S33.2
unnamed: D34.2 (A), S34.2
unnamed: D35.2 (A), S35.2
unnamed: D36.2 (A), S36.2
unnamed: D37.2 (A), S37.2
unnamed: D38.2 (A), S38.2
unnamed: D39.2 (A), S39.2
unnamed: D40.2 (A), S40.2
unnamed: D41.2 (A), S41.2
unnamed: D42.2 (A), S42.2
unnamed: D43.2 (A), S43.2
unnamed: D44.2 (A), S44.2
unnamed: D45.2 (A), S45.2
unnamed: D46.2 (A), S46.2
unnamed: D47.2 (A), S47.2
unnamed: D48.2 (A), S48.2
unnamed: D49.2 (A), S49.2
unnamed: D50.2 (A), S50.2
unnamed: D51.2 (A), S51.2
unnamed: D52.2 (A), S52.2
unnamed: D53.2 (A), S53.2
unnamed: D54.2 (A), S54.2
unnamed: D55.2 (A), S55.2
unnamed: D56.2 (A), S56.2
unnamed: D57.2 (A), S57.2
unnamed: D58.2 (A), S58.2
unnamed: D59.2 (A), S59.2
unnamed: D60.2 (A), S60.2
unnamed: D61.2 (A), S61.2
unnamed: D62.2 (A), S62.2
unnamed: D63.2 (A), S63.2
unnamed: D64.2 (A), S64.2
unnamed: D65.2 (A), S65.2
unnamed: D66.2 (A), S66.2
unnamed: D67.2 (A), S67.2
unnamed: D68.2 (A), S68.2
unnamed: D69.2 (A), S69.2
unnamed: D70.2 (A), S70.2
unnamed: D71.2 (A), S71.2
unnamed: D72.2 (A), S72.2
unnamed: D73.2 (A), S73.2
unnamed: D74.2 (A), S74.2
unnamed: D75.2 (A), S75.2
unnamed: D76.2 (A), S76.2
unnamed: D77.2 (A), S77.2
unnamed: D78.2 (A), S78.2
unnamed: D79.2 (A), S79.2
unnamed: D80.2 (A), S80.2
unnamed: D81.2 (A), S81.2
Row 1: D1.1 (K), D2.1 (K), D3.1 (K), D4.1 (K), D5.1 (K), D6.1 (K), D7.1 (K), D8.1 (K), D9.1 (K), D10.1 (K), D11.1 (K), D12.1 (K), D13.1 (K), D14.1 (K); also elsewhere on the board
Row 2: D15.1 (K), D16.1 (K), D17.1 (K), D18.1 (K), D19.1 (K), D20.1 (K), D21.1 (K), D22.1 (K), D23.1 (K), D24.1 (K), D25.1 (K), D26.1 (K), D27.1 (K), D28.1 (K), D29.1 (K); also elsewhere on the board
Row 3: D30.1 (K), D31.1 (K), D32.1 (K), D33.1 (K), D34.1 (K), D35.1 (K), D36.1 (K), D37.1 (K), D38.1 (K), D39.1 (K), D40.1 (K), D41.1 (K), D42.1 (K), D43.1 (K), D44.1 (K); also elsewhere on the board
Row 4: D45.1 (K), D46.1 (K), D47.1 (K), D48.1 (K), D49.1 (K), D50.1 (K), D51.1 (K), D52.1 (K), D53.1 (K), D54.1 (K), D55.1 (K), D56.1 (K), D57.1 (K), D58.1 (K); also elsewhere on the board
Row 5: D59.1 (K), D60.1 (K), D61.1 (K), D62.1 (K), D63.1 (K), D64.1 (K), D65.1 (K), D66.1 (K), D67.1 (K), D68.1 (K), D69.1 (K), D70.1 (K), D71.1 (K); also elsewhere on the board
Row 6: D72.1 (K), D73.1 (K), D74.1 (K), D75.1 (K), D76.1 (K), D77.1 (K), D78.1 (K), D79.1 (K), D80.1 (K), D81.1 (K); also elsewhere on the board

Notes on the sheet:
tab
num
sft
cap
spc

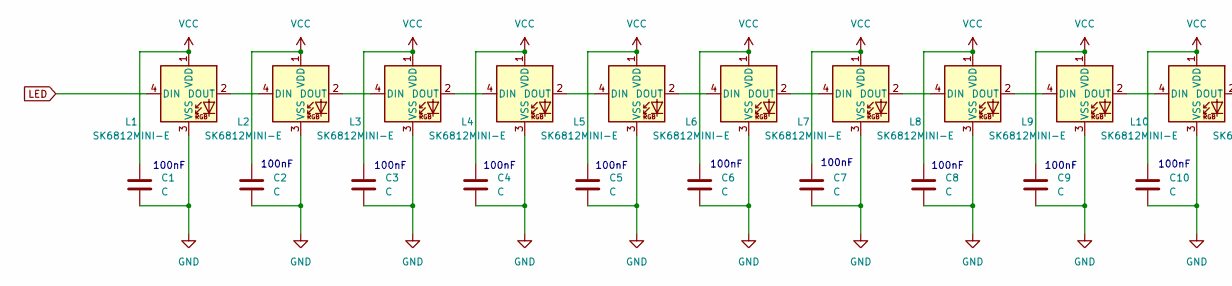
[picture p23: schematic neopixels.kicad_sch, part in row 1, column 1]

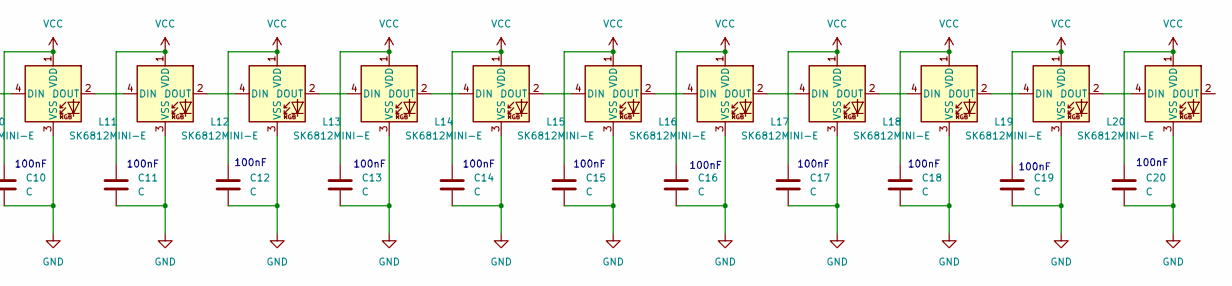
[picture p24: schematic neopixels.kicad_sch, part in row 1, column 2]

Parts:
C1, C2, C3, C4, C5, C6, C7, C8, C9, C10, C11, C12, C13, C14, C15, C16, C17, C18, C19, C20: C; CP_Radial_D5.0mm_P2.50mm
L1, L2, L3, L4, L5, L6, L7, L8, L9, L10, L11, L12, L13, L14, L15, L16, L17, L18, L19, L20: SK6812MINI-E; MX SK6812MINI E (1)

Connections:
LED: L1.4 (DIN); also elsewhere on the board
unnamed: L1.2 (DOUT), L2.4 (DIN)
unnamed: L2.2 (DOUT), L3.4 (DIN)
unnamed: L3.2 (DOUT), L4.4 (DIN)
unnamed: L4.2 (DOUT), L5.4 (DIN)
unnamed: L5.2 (DOUT), L6.4 (DIN)
unnamed: L6.2 (DOUT), L7.4 (DIN)
unnamed: L7.2 (DOUT), L8.4 (DIN)
unnamed: L8.2 (DOUT), L9.4 (DIN)
unnamed: L9.2 (DOUT), L10.4 (DIN)
unnamed: L10.2 (DOUT), L11.4 (DIN)
unnamed: L11.2 (DOUT), L12.4 (DIN)
unnamed: L12.2 (DOUT), L13.4 (DIN)
unnamed: L13.2 (DOUT), L14.4 (DIN)
unnamed: L14.2 (DOUT), L15.4 (DIN)
unnamed: L15.2 (DOUT), L16.4 (DIN)
unnamed: L16.2 (DOUT), L17.4 (DIN)
unnamed: L17.2 (DOUT), L18.4 (DIN)
unnamed: L18.2 (DOUT), L19.4 (DIN)
unnamed: L19.2 (DOUT), L20.4 (DIN)
RE_SW_2: C1.2, C2.2, C3.2, C4.2, C5.2, C6.2, C7.2, C8.2, C9.2, C10.2, C11.2, C12.2, C13.2, C14.2, C15.2, C16.2, C17.2, C18.2, C19.2, C20.2, L1.3 (VSS), L2.3 (VSS), L3.3 (VSS), L4.3 (VSS), L5.3 (VSS), L6.3 (VSS), L7.3 (VSS), L8.3 (VSS), L9.3 (VSS), L10.3 (VSS), L11.3 (VSS), L12.3 (VSS), L13.3 (VSS), L14.3 (VSS), L15.3 (VSS), L16.3 (VSS), L17.3 (VSS), L18.3 (VSS), L19.3 (VSS), L20.3 (VSS); also elsewhere on the board
VCC: C1.1, C2.1, C3.1, C4.1, C5.1, C6.1, C7.1, C8.1, C9.1, C10.1, C11.1, C12.1, C13.1, C14.1, C15.1, C16.1, C17.1, C18.1, C19.1, C20.1, L1.1 (VDD), L2.1 (VDD), L3.1 (VDD), L4.1 (VDD), L5.1 (VDD), L6.1 (VDD), L7.1 (VDD), L8.1 (VDD), L9.1 (VDD), L10.1 (VDD), L11.1 (VDD), L12.1 (VDD), L13.1 (VDD), L14.1 (VDD), L15.1 (VDD), L16.1 (VDD), L17.1 (VDD), L18.1 (VDD), L19.1 (VDD), L20.1 (VDD); also elsewhere on the board

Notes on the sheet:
100nF

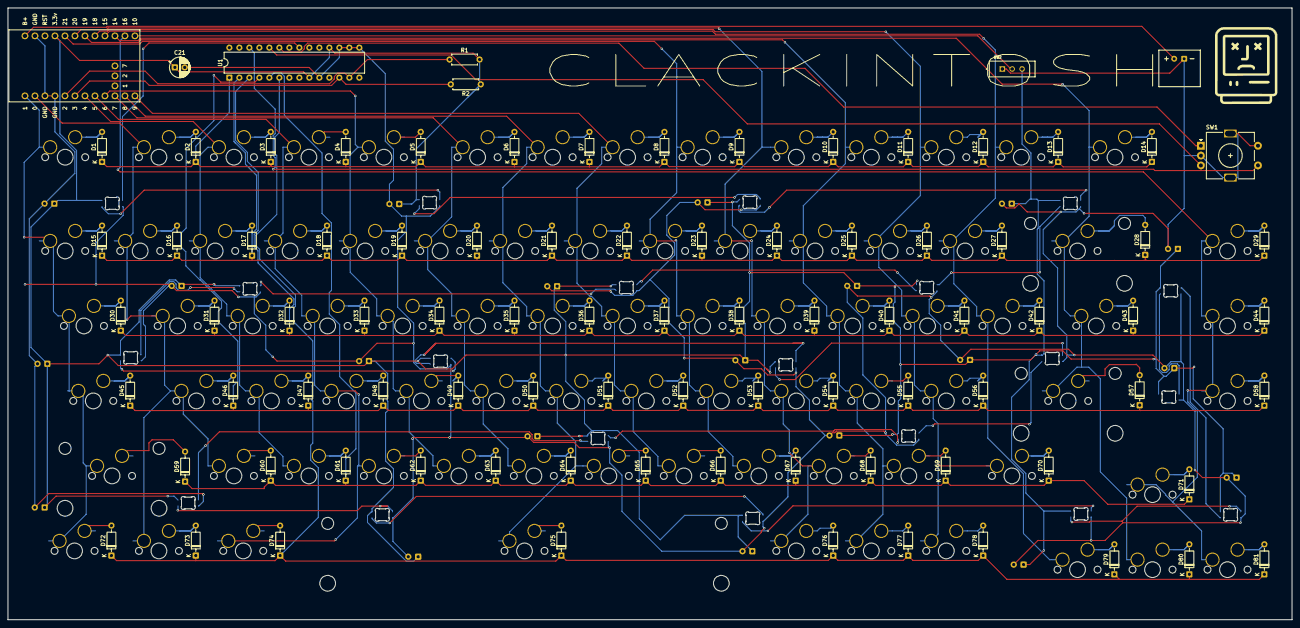
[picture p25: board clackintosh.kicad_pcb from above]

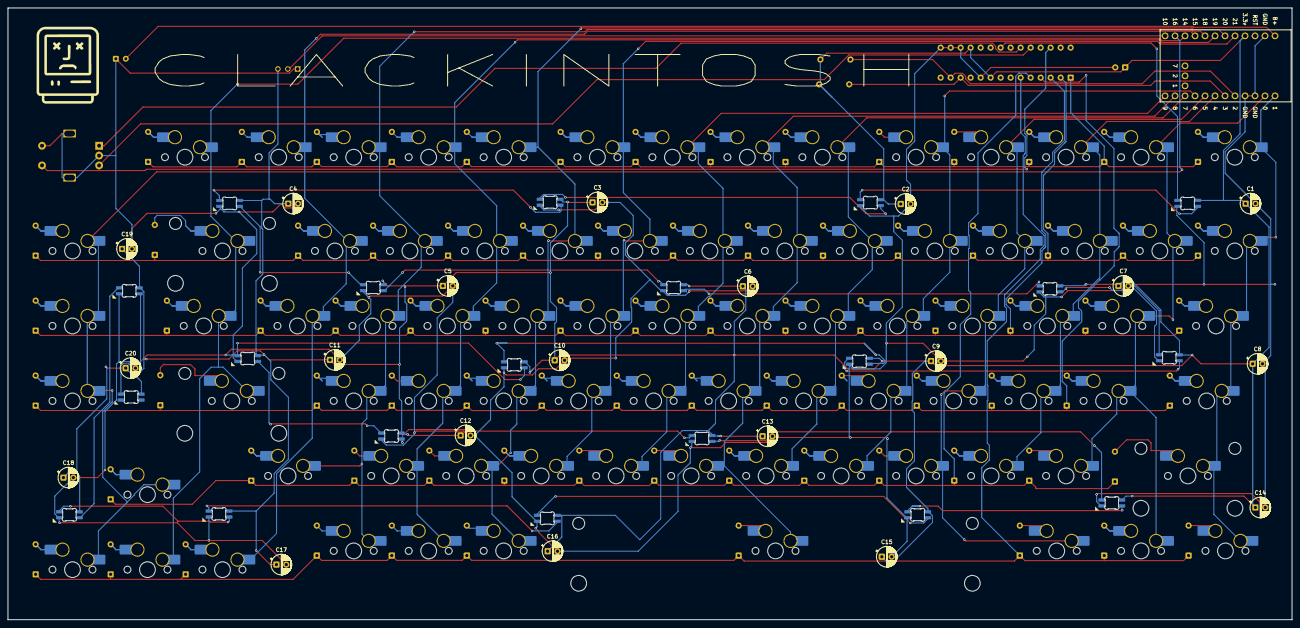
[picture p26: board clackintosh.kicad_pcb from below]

Board: 2 copper layers, 326.2 x 155.4 mm, 210 parts (101 on the bottom side), 131 nets.

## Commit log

2025-07-30 initial version keeb pcb files
    [MINI-SPDT-SW.step, SK6812-E.step, clackintosh.kicad_pcb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]
2025-07-31 final files
    [MINI SPDT SW 3D Model STEP 56544.STEP, Plate.dxf, SK6812-E.step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]
2025-08-01 after-review updates
    [MINI SPDT SW 3D Model STEP 56544.STEP, MINI-SPDT-SW.step, RE_knob.stl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]
